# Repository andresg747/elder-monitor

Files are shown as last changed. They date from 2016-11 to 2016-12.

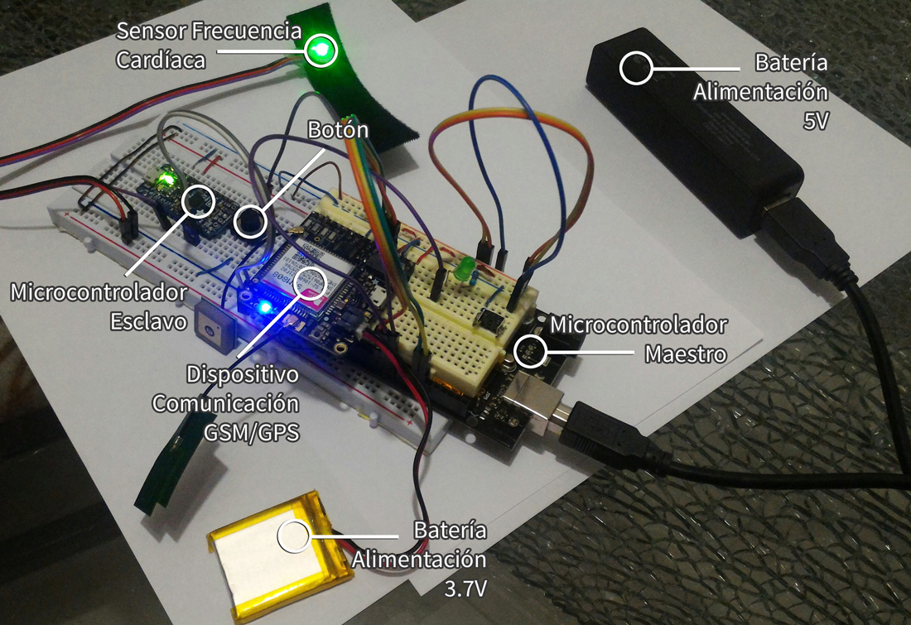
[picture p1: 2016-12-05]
Imágenes/Fotografia-descriptiva.jpg

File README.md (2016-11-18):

# Elder-Monitor
Dispositivo de monitorización para personas mayores. Localización GPS, lectura de frecuencia cardíaca, y botón de pánico con alertas vía SMS.

Arduino + Módulo GPS/GSM FONA (Adafruit) + PulseSensor (Adafruit). 

Proyecto para la acreditación de grado universitario.
Carrera: Ingeniería Electrónica en Computación.
Universidad Yacambu - Cabudare Edo. Lara, Venezuela.

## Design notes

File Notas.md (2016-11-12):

#### 09/10 2:49am
**Primera prueba - Botón de Pánico**

Al pulsar botón por 3 segundos, el led indicador enciende. Al soltarlo realiza las siguientes funciones:
+ Query de localización al módulo FONA.
+ Si el query es exitoso (GPSFIX), procede a enviar un msj de texto al número pregrabado con un mensaje de texto y un link (gmaps) con la localización exacta.

### 10/10 1:00am
**Mejorando Botón de Pánico**

Al pulsar el botón:

1. Chequea si hay GPSFIX y Envía Mensaje:
   + Si hay, actualiza latitud y longitud. Escribe en Serial. Actualiza IoT. Concatena valores al SMS y envía mensaje SOS.
   + Si no hay GPSFIX envía mensaje SOS invitando a revisar io.adafruit para chequear última localización disponible. Se mantendrá buscando hasta tener GPSFIX de nuevo y vuelve a enviar mensaje con localización "Nueva localización disponible: xxxxxxxxxxx ". (Recomendacion, flag en main loop).

### 10/10 2:00am

Creadas rutinas que se ejecutarán cada 15 seg y 60 seg respectivamente.
Para actualizar de manera constante Localización, Batería y (posteriormente) BPM.

### 12/10 11:30am
Agregado nuevo flag para enviar un único mensaje de alerta si el GPS no está disponible en ese instante. El mensaje invita al supervisor a revisar la última localización disponible en io.adafruit.com/andresg747/feeds/location

Se hicieron pruebas exitosas con función botón de pánico.

### 02/11 11:00pm
Al detectar fallas en tiempo de ejecución, se determinó que el stack de la SRAM estaba colapsando.
Se limpiaron variables y funciones varias intentando disminuir el espacio de almacenamiento utilizado por la SRAM y se corrigieron los fallos.
Se agregó una función de lectura de SMS que detecta comandos (.STATUS y .NUMERO) enviados por el supervisor y responde con SMS dependiendo del caso.

De igual manera, el espacio utilizado en SRAM sigue siendo alto. Aún falta agregar la lectura y cálculo de la frecuencia cardíaca.
Existe la probabilidad de que al agregar esta funcionalidad, la SRAM llegue a un nivel crítico que ponga en riesgo la estabilidad de la ejecución del programa

### 05/11 4:00pm
Se detectó un error que evitaba la conexión con el servidor de adafruit.io (MQTT broker) y cuya 'solución' fué des-comentar la línea #37 de la librería Adafruit_MQTT.h
Solución tomada del reporte del issue: https://github.com/adafruit/Adafruit_MQTT_Library/issues/54
Esta línea de código `#define MQTT_DEBUG` añade comentarios adicionales en la comunicación serial, referentes al envío de paquetes vía el protocolo MQTT. En el caso de este proyecto, se puede observar los paquetes enviados para localización, batería y BPM.

Se agregó un flag para el caso en el que se solicita .STATUS via SMS y ya se envió respuesta cuando no hay GPSFIX pero sin el flag nunca se enviaba el nuevo mensaje con la localización cuando se alcanzaba la conexión GPS.

**Sobre el uso de otro microcontrolador**
Como fué indicado anteriormente, se realizaron ciertos cambios en el código para optimizar el uso del espacio de almacenamiento, tanto en la memoria de programa (FLASH) pero principalmente en la memoria de ejecución (SRAM), del microcontrolador. Se determinó que el desbordamiento, o la sobre saturación de esta última memoria era la causante de que el programa en un momento determinado se reseteara.

Luego de ciertos cambios que se pueden observar en 4e97dd7, se eliminaron funciones inutilizadas, se redujo el espacio utilizado por variables cambiando su tipo a uno más eficiente y se evitó el uso de variables dinámicas. Esto aumentó el espacio de SRAM libre a casi 20%. Luego de este cambio, el dispositivo no volvió a resetearse de manera involuntaria.

Aún el proyecto, como está, no ha sido terminado. Se debe agregar una funcionalidad más para cubrir con los objetivos propuestos: **el sensor de frecuencia cardíaca**. Al revisar la librería utilizada por este sensor, se puede notar que su adición causaría, de nuevo, problemas de espacio en la SRAM. 

Dicho esto, por el poco tiempo que queda para la presentación del prototipo, surge la necesidad de agregar un segundo microcontrolador quedando el esquema de trabajo de la siguiente manera:

	+ Arduino Nano (ATMEGA328P 5V/16MHz) - Principal: Encargado del manejo del módulo de comunicación GSM/GPS, del procesamiento principal de variables y de la toma de decisiones en general.
	+ Trinket Pro (ATMEGA328P 5V/16MHz) - Secundario: Tiene como tarea única tarea el cálculo de la frecuencia cardíaca, y el envío de la misma a través de un canal serial hacia el microcontrolador principal.

El microcontrolador principal, se comunicará con el módulo FONA a través del un canal de SoftwareSerial (pines 10 y 11), y con el microcontrolador secundario a través del HardwareSerial (pines 0 y 1).

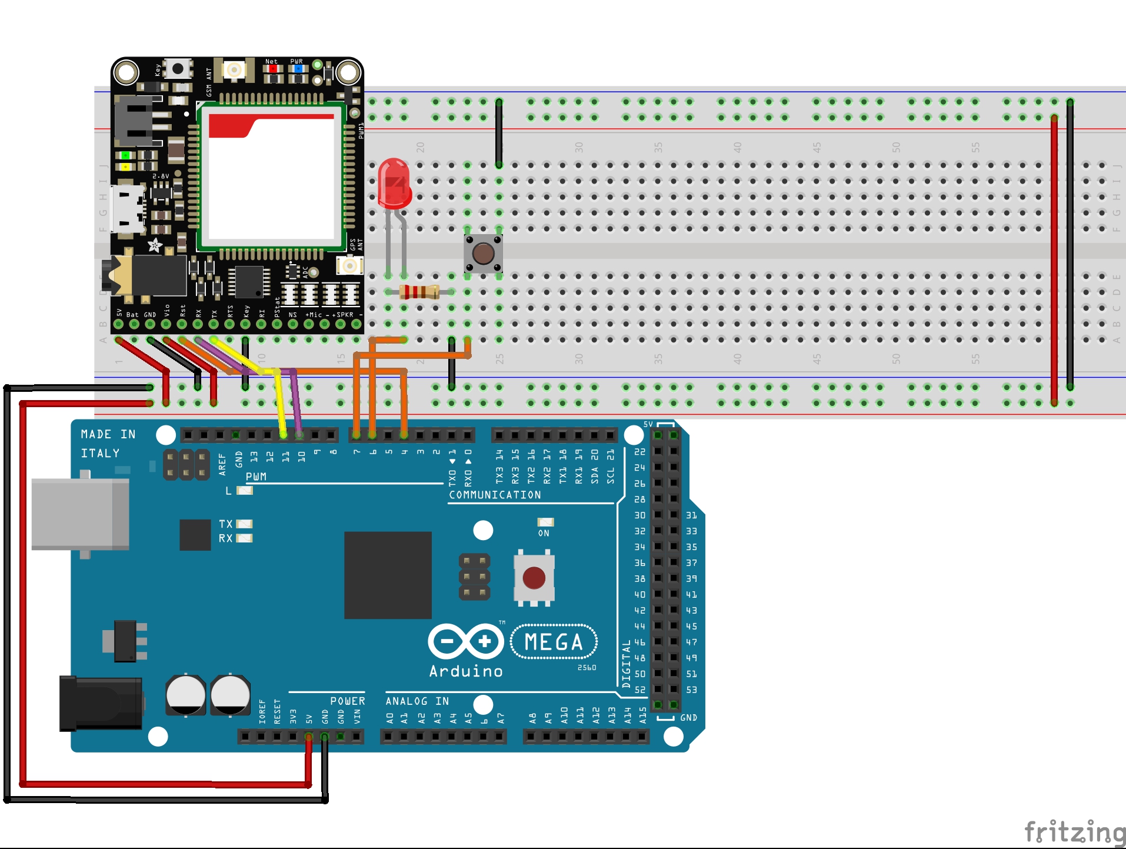
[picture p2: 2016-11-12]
Imágenes/fritzing-sketch_bb.jpg

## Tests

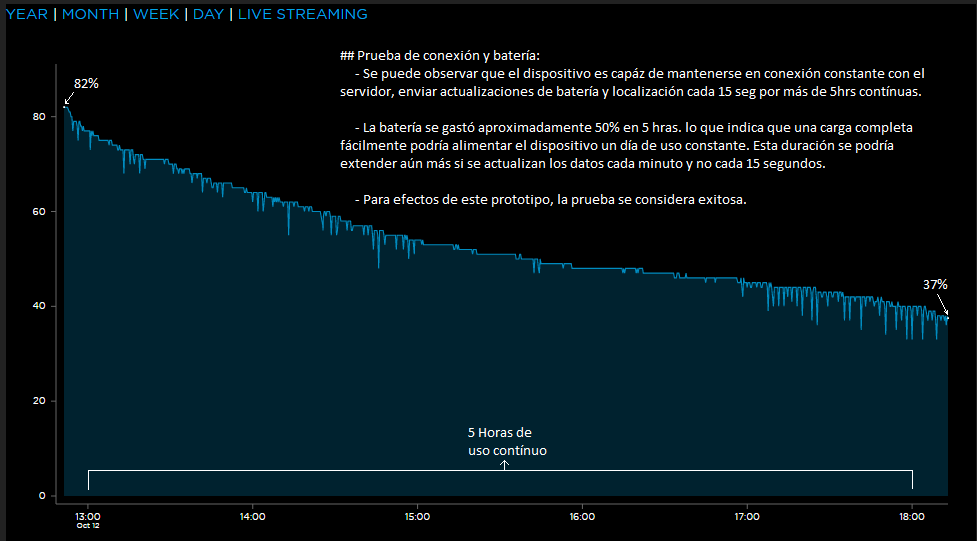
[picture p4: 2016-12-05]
Imágenes/Prueba Batería.png

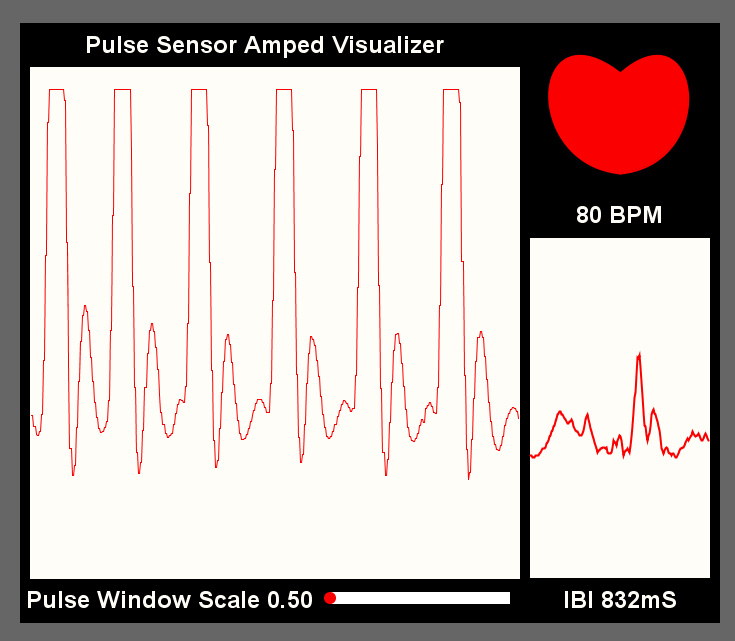
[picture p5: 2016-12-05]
Imágenes/BPM Prueba.png

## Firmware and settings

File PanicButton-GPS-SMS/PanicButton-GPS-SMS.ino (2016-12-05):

// Trabajo de Grado
// Andrés García

// Libraries
#include <Adafruit_SleepyDog.h>
#include <SoftwareSerial.h>
#include "Adafruit_FONA.h"
#include "Adafruit_MQTT.h"
#include "Adafruit_MQTT_FONA.h"
#include <Wire.h>

// Variables
int ledPin = 7;
int blinkPin = 9;
int buttonPin = 6;
int current;        // Estado del botón, activo en bajo
char bpm_chr = "";
int bpm = 0;
char bpm_string[3];
long millis_held;   // Milisegundos transcurridos
long secs_held;
long prev_secs_held;
byte previous = HIGH;
unsigned long firstTime;
char replybuffer[100];
byte SOS_flag=0; // Por si se intentó enviar SOS y aún no se tiene GPSFIX o nó se pudo enviar para reintentarlo
byte aux_Enviar_SMS = 0;
byte aux_Enviar_SMS_STATUS = 0;
byte STATUS_flag = 0;
uint16_t vbat;
float latitude, longitude, speed_kph, heading, altitude;
int smsnum; // Número de SMS en SIMCARD
// Para lectura SMS comando
char *num1 ="+584245328127";
char *num2;
char *num3;
char *num4;
char *num5;
char mensaje_txt[160];
char sender[13];

#define quinceSeg (1000UL * 15) // Base rutina c/15 Seg
#define unMin (1000UL * 60)  // Base rutina c/1 min
static unsigned long aux60 = 0 - unMin;
static unsigned long aux15 = 0 - quinceSeg;

// FONA pins
#define FONA_RX              11   // FONA serial RX pin.
#define FONA_TX              10   // FONA serial TX pin.
#define FONA_RST             5   // FONA reset pin

// FONA GPRS
#define FONA_APN             "internet.movistar.ve"
#define FONA_USERNAME        ""
#define FONA_PASSWORD        ""

// Adafruit IO
#define AIO_SERVER           "io.adafruit.com" 
#define AIO_SERVERPORT       1883
#define AIO_USERNAME         "andresg747"
#define AIO_KEY              "775d7bcfc4524333b664b941f3d82a1e"

// #define MAX_TX_FAILURES      3  // Maximum number of publish failures in a row before resetting the whole sketch.

// FONA instance & configuration
SoftwareSerial fonaSS = SoftwareSerial(FONA_TX, FONA_RX);     // FONA software serial connection.
Adafruit_FONA fona = Adafruit_FONA(FONA_RST);                 // FONA library connection.

Adafruit_MQTT_FONA mqtt(&fona, AIO_SERVER, AIO_SERVERPORT, AIO_USERNAME, AIO_KEY);

uint8_t txFailures = 0; // Cuantos publish fallidos consecutivos han ocurrido 

// Feeds
Adafruit_MQTT_Publish location_feed = Adafruit_MQTT_Publish(&mqtt, AIO_USERNAME "/feeds/location/csv");
Adafruit_MQTT_Publish battery_feed = Adafruit_MQTT_Publish(&mqtt, AIO_USERNAME "/feeds/battery");
Adafruit_MQTT_Publish bpm_feed = Adafruit_MQTT_Publish(&mqtt, AIO_USERNAME "/feeds/bpm");

void setup() {
  pinMode(blinkPin, OUTPUT);        // pin that will blink to your heartbeat!
  pinMode(ledPin, OUTPUT);
  digitalWrite(buttonPin, HIGH);  // Enciende PullUp 
  digitalWrite(ledPin,LOW);

  //Wire
  Wire.begin();        // Inicializa comunicación I2C

  //Inicializa Puerto Serial y Conexión Módulo
  Serial.begin(115200);
  Serial.println(F("Inicializando (puede tardar hasta 10 seg)"));
  fonaSS.begin(4800);
  if (!fona.begin(fonaSS)) {
    halt(F("FONA no disponible"));
  }

  Serial.println(F("FONA Conectado!"));

  // Wait for FONA to connect to cell network (up to 8 seconds, then watchdog reset).
  Serial.println(F("Conectando a la red..."));
  while (fona.getNetworkStatus() != 1) {
    delay(500);
  }
  fona.setGPRSNetworkSettings(F(FONA_APN));
  delay(1000);
  Serial.println(F("Dehabilita GPRS"));
  fona.enableGPRS(false);
  delay(1000);
  Serial.println(F("Habilita GPRS"));
  while (!fona.enableGPRS(true)) {
    Serial.println(F("No se pudo conectar a la red de datos..."));
    delay(1000);
    Serial.println(F("Dehabilita GPRS"));
    fona.enableGPRS(false);
    delay(1000);
  }
  Serial.println(F("Conectado a la red de datos."));
  delay(1000);

  // Now make the MQTT connection.
  int8_t ret = mqtt.connect();
  if (ret != 0) {
    Serial.println(mqtt.connectErrorString(ret));
    Serial.println(F("No se pudo conectar a servidor MQTT..."));
  }
  Serial.println(F("MQTT Conectado!"));

  // Initial GPS read
  bool gpsFix = fona.getGPS(&latitude, &longitude, &speed_kph, &heading, &altitude);

  // Enable GPS.
  fona.enableGPS(true);

  delay(500);

  borrarSMS();
  checkGPS();
}

void loop() {
  //MQTT_connect();
  checkbutton();

  if ((long)(millis() - aux60) >= unMin){
    aux60 += unMin;
    // ++++++++  Cada 60 seg
    checkGPS();
    checkBattery();

  }else if((long)(millis() - aux15) >= quinceSeg){
    aux15 += quinceSeg;
    // ++++++++  Cada 15 seg
    checkBPM();
    leerSMS();

    //Veriicamos flag para envío de SMS Alerta
    if(SOS_flag == 1){
      sendSMS_SOS();
    }
    if(STATUS_flag){
      sendSMS_STATUS();
    }
  }

  delay(10);
}

void leerSMS(){
  smsnum = fona.getNumSMS();
  if(smsnum > 0){
    Serial.println(F("Nuevo Mensaje de Texto"));
    uint8_t n = 1; 
    while (true) {
      uint16_t smslen;

      Serial.print(F("\n\rReading SMS #")); Serial.println(n);
     uint8_t len = fona.readSMS(n, replybuffer, 250, &smslen); // pass in buffer and max len!
     // if the length is zero, its a special case where the index number is higher
     // so increase the max we'll look at!
     if (len == 0) {
      Serial.println(F("[empty slot]"));
      n++;
      continue;
     }
     if (! fona.getSMSSender(n, sender, sizeof(sender))) {
       // failed to get the sender?
      sender[0] = 0;
     }

     Serial.print(F("***** SMS #")); Serial.print(n);
     Serial.print(" ("); Serial.print(len); Serial.println(F(") bytes *****"));
     Serial.println(replybuffer);
     Serial.print(F("From: ")); Serial.println(sender);
     Serial.println(F("*****"));
     String mensaje = replybuffer;

     // if (strcasecmp(replybuffer, ".STATUS") == 0) {
     if (mensaje.substring(0, 7) == ".STATUS") {
       // Comando Status
      Serial.println(F("/////////////////////"));
      Serial.println(F("Solicita Status"));
      aux_Enviar_SMS_STATUS = 1;
      sendSMS_STATUS();
     }
     // if (strcasecmp(replybuffer, ".NUMERO") == 0) {
     if (mensaje.substring(0, 7) == ".NUMERO") {
      // Comando Cambiar Número
      Serial.println(F("Comenzando parsing..."));

      delay(500);
      char *token;
      token = strtok(replybuffer,",");
      if (token == NULL){
        Serial.println(F("No hay tokens."));
        break;
      }
      num1 = token;
      strncpy(num1,num1+8,14);
      Serial.print("Numero 1: ");
      Serial.println(num1);
      delay(500);

      token = strtok(NULL,",");
      num2 = token;
      Serial.print("Numero 2: ");
      Serial.println(num2);
      delay(500);

      token = strtok(NULL,",");
      num3 = token;
      Serial.print("Numero 3: ");
      Serial.println(num3);
      delay(500);

      token = strtok(NULL,",");
      num4 = token;
      Serial.print("Numero 4: ");
      Serial.println(num4);
      delay(500);

      token = strtok(NULL,",");
      num5 = token;
      Serial.print("Numero 5: ");
      Serial.println(num5);
      delay(1000);
     }

     delay(2000);
     break;
   } 
   borrarSMS(); 
 }
 Serial.print(F("Hay "));
 Serial.print((smsnum));
 Serial.println(F(" SMS's en la SIM CARD."));
}

void checkbutton(){
  current = digitalRead(buttonPin);

  // if the button state changes to pressed, remember the start time 
  if (current == LOW && previous == HIGH && (millis() - firstTime) > 200) {
    firstTime = millis();
  }

  millis_held = (millis() - firstTime);
  secs_held = millis_held / 1000;
  // Chequea si el botón realmente fue pulsado (debounce)
  if (millis_held > 50) {
    // Pulsado por más de 2800ms
    if (current == LOW && secs_held > prev_secs_held ) {
      if (millis_held > 2900 )
      {
        digitalWrite(ledPin,HIGH);
      }
    }
    if (current == HIGH && previous == LOW) {
      if (millis_held >= 3000) {
        aux_Enviar_SMS = 1;
        sendSMS_SOS();
      }
    }
  }

  previous = current;
  prev_secs_held = secs_held;

  if(current == HIGH)
    digitalWrite(ledPin,LOW);
}

// Envio Mensaje Socorro
void sendSMS_SOS(){
  // Lectura GPS
  bool gpsFix = fona.getGPS(&latitude, &longitude, &speed_kph, &heading, &altitude);

  if(gpsFix){
    Serial.print(F("Latitud: "));
    Serial.print(latitude, 5);
    Serial.println("");

    Serial.print(F("Longitud: "));
    Serial.print(longitude, 5);
    Serial.println("");

    // Concateno mensaje con Latitud y Longitud
    strcpy(mensaje_txt, "SOS! Ubicacion: https://maps.google.com/?q=");
    dtostrf(latitude,6,5,&mensaje_txt[strlen(mensaje_txt)]);
    strcat(mensaje_txt,",");
    dtostrf(longitude,6,5,&mensaje_txt[strlen(mensaje_txt)]);
    if(bpm == 0){
      strcat(mensaje_txt," BPM no disponible.");
    }else{
      sprintf(bpm_string, "%d", bpm);
      strcat(mensaje_txt," BPM: ");
      strcat(mensaje_txt,bpm_string);
      strcat(mensaje_txt," ");
    }

    // Imprimo mensaje en serial
    Serial.println(mensaje_txt);

    // Enviar mensaje a todos
    if (strlen(num1) > 1){
      if (!fona.sendSMS(num1, mensaje_txt)) {
        Serial.println(F("No se pudo enviar SMS"));
        SOS_flag = 1;
      } else {
        Serial.println(F("Mensaje enviado con exito!"));
        SOS_flag = 0;
        aux_Enviar_SMS = 0;
      }
    }
    if (strlen(num2) > 1){
      if (!fona.sendSMS(num2, mensaje_txt)) {
        Serial.println(F("No se pudo enviar SMS"));
      } else {
        Serial.println(F("Mensaje enviado con exito!"));
      }
    }
    if (strlen(num3) > 1){
      if (!fona.sendSMS(num3, mensaje_txt)) {
        Serial.println(F("No se pudo enviar SMS"));
      } else {
        Serial.println(F("Mensaje enviado con exito!"));
      }
    }
    if (strlen(num4) > 1){
      if (!fona.sendSMS(num4, mensaje_txt)) {
        Serial.println(F("No se pudo enviar SMS"));
      } else {
        Serial.println(F("Mensaje enviado con exito!"));
      }
    }
    if (strlen(num5) > 1){
      if (!fona.sendSMS(num5, mensaje_txt)) {
        Serial.println(F("No se pudo enviar SMS"));
      } else {
        Serial.println(F("Mensaje enviado con exito!"));
      }
    }

    // Actualiza IoT
  }else if (!gpsFix){

    SOS_flag = 1;
    Serial.println(F("Para SMS-SOS Aun no hay GPSFIX, se intentara de nuevo. "));
    if(aux_Enviar_SMS){
      Serial.println("Creando nuevo mensaje");delay(100);
      strcpy(mensaje_txt, "SOS! GPS no disponible. Ultima ubicacion: https://io.adafruit.com/andresg747/ Se notificara cuando GPS este disponible. ");
      if(bpm == 0){
        strcat(mensaje_txt," BPM no disponible.");
      }else{
        sprintf(bpm_string, "%d", bpm);
        strcat(mensaje_txt," BPM: ");
        strcat(mensaje_txt,bpm_string);
        strcat(mensaje_txt," ");
      }
      // Enviar a todos los números:
      if (strlen(num1) > 1){
        if (!fona.sendSMS(num1, mensaje_txt)) {
          Serial.println(F("No se pudo enviar SMS"));
        } else {
          Serial.println(F("Mensaje enviado con exito!"));
          aux_Enviar_SMS = 0;
        }
      }
      if (strlen(num2) > 2){
        if (!fona.sendSMS(num2, mensaje_txt)) {
          Serial.println(F("No se pudo enviar SMS"));
        } else {
          Serial.println(F("Mensaje enviado con exito!"));
        }
      }
      if (strlen(num3) > 2){
        if (!fona.sendSMS(num3, mensaje_txt)) {
          Serial.println(F("No se pudo enviar SMS"));
        } else {
          Serial.println(F("Mensaje enviado con exito!"));
        }
      }
      if (strlen(num4) > 2){
        if (!fona.sendSMS(num4, mensaje_txt)) {
          Serial.println(F("No se pudo enviar SMS"));
        } else {
          Serial.println(F("Mensaje enviado con exito!"));
        }
      }
      if (strlen(num5) > 2){
        if (!fona.sendSMS(num5, mensaje_txt)) {
          Serial.println(F("No se pudo enviar SMS"));
        } else {
          Serial.println(F("Mensaje enviado con exito!"));
        }
      }
    }
  }
}

// Envio Mensaje Previa solicitud STATUS
void sendSMS_STATUS(){
  // Lectura GPS
  bool gpsFix = fona.getGPS(&latitude, &longitude, &speed_kph, &heading, &altitude);

  if(gpsFix){
    // Concateno mensaje con Latitud y Longitud
    strcpy(mensaje_txt, "Ubicacion: https://maps.google.com/?q=");
    dtostrf(latitude,6,5,&mensaje_txt[strlen(mensaje_txt)]);
    strcat(mensaje_txt,",");
    dtostrf(longitude,6,5,&mensaje_txt[strlen(mensaje_txt)]);
    if(bpm == 0){
      strcat(mensaje_txt," BPM no disponible.");
    }else{
      sprintf(bpm_string, "%d", bpm);
      strcat(mensaje_txt," BPM: ");
      strcat(mensaje_txt,bpm_string);
      strcat(mensaje_txt," ");
    }

    // Imprimo mensaje en serial
    Serial.println(mensaje_txt);

    //Envío mensaje

    if (!fona.sendSMS(sender, mensaje_txt)) {
      Serial.println(F("No se pudo enviar SMS"));
    } else {
      Serial.println(F("Mensaje enviado con exito!"));
      STATUS_flag = 0;
    }

    // Actualiza IoT
  }else if (!gpsFix){
    STATUS_flag = 1;
    Serial.println(F("Para SMS-STATUS Aun no hay GPSFIX, se intentara de nuevo."));
    if(aux_Enviar_SMS_STATUS){
      strcpy(mensaje_txt, "GPS no disponible. Ultima ubicacion: https://io.adafruit.com/andresg747/ Se notificara de inmediato cuando GPS este disponible. ");
      if(bpm == 0){
        strcat(mensaje_txt," BPM no disponible.");
      }else{
        sprintf(bpm_string, "%d", bpm);
        strcat(mensaje_txt," BPM: ");
        strcat(mensaje_txt,bpm_string);
        strcat(mensaje_txt," ");
      }

      if (!fona.sendSMS(sender, mensaje_txt)) {
        Serial.println(F("No se pudo enviar SMS"));
      } else {
        Serial.println(F("Mensaje enviado con exito!"));
        aux_Enviar_SMS_STATUS = 0;
      }

    }
  }
}

// Lectura y actualización de GPS
void checkGPS(){
  bool gpsFix = fona.getGPS(&latitude, &longitude, &speed_kph, &heading, &altitude);

  if(gpsFix){
    Serial.print(F("Latitud: "));
    Serial.print(latitude, 5);
    Serial.println("");

    Serial.print(F("Longitud: "));
    Serial.print(longitude, 5);
    Serial.println("");

    // Actualiza IoT
    logLocation(latitude, longitude, altitude, location_feed);

  }else{
    Serial.println(F("GPS No disponible."));
  }
}

void checkBattery(){
  if (! fona.getBattPercent(&vbat)) {
    Serial.println(F("No pudo obtener nivel de Bateria"));
  } else {
    Serial.print(F("Porcentaje Bateria = ")); Serial.print(vbat); Serial.println(F("%"));
  }
  log(vbat, battery_feed);
}

void checkBPM(){
  Serial.println(F("Solicitando BPM"));
  Wire.requestFrom(1, 1);     // Solicita 1 byte de dispositivo esclavo #1
  while (Wire.available()) {
    bpm_chr = Wire.read();
    bpm = (int)bpm_chr;
    if(bpm > 165 || bpm < 35){
      Serial.println("BPM: No Disponible.");
      bpm = 0;
    }else{
      Serial.print("BPM: ");
      Serial.println(bpm);
      log(bpm, bpm_feed);
    }
  }
}

// Manejo de errores
void halt(const __FlashStringHelper *error) {
  Serial.println(error);
  while (1) {
    digitalWrite(ledPin, LOW);
    delay(100);
    digitalWrite(ledPin, HIGH);
    delay(100);
  }
}

// Log battery
void log(uint32_t indicator, Adafruit_MQTT_Publish& publishFeed) {
  // Publish
  Serial.print(F("Publicando ")); Serial.println(indicator);
  if (!publishFeed.publish(indicator)) {
    Serial.println(F("Publish failed!"));
    txFailures++;
  }
  else {
    Serial.println(F("Publish succeeded!"));
    txFailures = 0;
  }
}

// Serialize the lat, long, altitude to a CSV string that can be published to the specified feed.
void logLocation(float latitude, float longitude, float altitude, Adafruit_MQTT_Publish& publishFeed) {
  // Initialize a string buffer to hold the data that will be published.
  char sendBuffer[120];
  memset(sendBuffer, 0, sizeof(sendBuffer));
  int index = 0;

  // Start with '0,' to set the feed value.  The value isn't really used so 0 is used as a placeholder.
  sendBuffer[index++] = '0';
  sendBuffer[index++] = ',';

  // Now set latitude, longitude, altitude separated by commas.
  dtostrf(latitude, 2, 6, &sendBuffer[index]);
  index += strlen(&sendBuffer[index]);
  sendBuffer[index++] = ',';
  dtostrf(longitude, 3, 6, &sendBuffer[index]);
  index += strlen(&sendBuffer[index]);
  sendBuffer[index++] = ',';
  dtostrf(altitude, 2, 6, &sendBuffer[index]);

  // Finally publish the string to the feed.
  Serial.print(F("Publicando Localizacion: "));
  Serial.println(sendBuffer);
  if (!publishFeed.publish(sendBuffer)) {
    Serial.println(F("Publish failed!"));
    txFailures++;
  }
  else {
    Serial.println(F("Publish succeeded!"));
    txFailures = 0;
  }
}

void borrarSMS(){
  smsnum = fona.getNumSMS();
  Serial.print(F("Hay "));
  Serial.print((smsnum));
  Serial.println(F(" SMS's en la SIM CARD."));
  if(smsnum > 0){
    for (int n = 1; n <= smsnum; ++n)
    {
      Serial.println(F("Borrando Mensaje #: "));
      Serial.println((n));
      fona.deleteSMS(n);
      delay(2000);
    }
  }
}

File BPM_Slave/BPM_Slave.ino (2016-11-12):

/*  Pulse Sensor Amped 1.4    by Joel Murphy and Yury Gitman   http://www.pulsesensor.com

  ----------------------  Notes ----------------------  ----------------------
  This code:
  1) Blinks an LED to User's Live Heartbeat   PIN 13
  2) Fades an LED to User's Live HeartBeat
  3) Determines BPM
  4) Prints All of the Above to Serial

  Read Me:
  https://github.com/WorldFamousElectronics/PulseSensor_Amped_Arduino/blob/master/README.md
  ----------------------       ----------------------  ----------------------
*/

#include <Wire.h>
// SDA PIN 4
// SCL PIN 5

//  Variables
int pulsePin = 0;                 // Pulse Sensor purple wire connected to analog pin 0
int blinkPin = 13;                // pin to blink led at each beat
int fadePin = 5;                  // pin to do fancy classy fading blink at each beat
int fadeRate = 0;                 // used to fade LED on with PWM on fadePin

// Volatile Variables, used in the interrupt service routine!
volatile int BPM = 0;                   // int that holds raw Analog in 0. updated every 2mS
volatile int Signal;                // holds the incoming raw data
volatile int IBI = 600;             // int that holds the time interval between beats! Must be seeded!
volatile boolean Pulse = false;     // "True" when User's live heartbeat is detected. "False" when not a "live beat".
volatile boolean QS = false;        // becomes true when Arduoino finds a beat.

// Regards Serial OutPut  -- Set This Up to your needs
static boolean serialVisual = false;   // Set to 'false' by Default.  Re-set to 'true' to see Arduino Serial Monitor ASCII Visual Pulse


void setup() {
  Wire.begin(1);                // join i2c bus with address #1
  Wire.onRequest(requestEvent); // register event
  pinMode(blinkPin, OUTPUT);        // pin that will blink to your heartbeat!
  pinMode(fadePin, OUTPUT);         // pin that will fade to your heartbeat!
  Serial.begin(115200);             // we agree to talk fast!
  interruptSetup();                 // sets up to read Pulse Sensor signal every 2mS
  // IF YOU ARE POWERING The Pulse Sensor AT VOLTAGE LESS THAN THE BOARD VOLTAGE,
  // UN-COMMENT THE NEXT LINE AND APPLY THAT VOLTAGE TO THE A-REF PIN
  //   analogReference(EXTERNAL);
}


//  Where the Magic Happens
void loop() {

  //serialOutput() ;

  if (QS == true) {    // A Heartbeat Was Found
    // BPM and IBI have been Determined
    // Quantified Self "QS" true when arduino finds a heartbeat
    fadeRate = 255;         // Makes the LED Fade Effect Happen
    // Set 'fadeRate' Variable to 255 to fade LED with pulse
    //serialOutputWhenBeatHappens();   // A Beat Happened, Output that to serial.
    QS = false;                      // reset the Quantified Self flag for next time
  }

  //ledFadeToBeat();                      // Makes the LED Fade Effect Happen
  delay(20);                             //  take a break
}

void requestEvent() {
  Wire.write(BPM);
}

void ledFadeToBeat() {
  fadeRate -= 15;                         //  set LED fade value
  fadeRate = constrain(fadeRate, 0, 255); //  keep LED fade value from going into negative numbers!
  analogWrite(fadePin, fadeRate);         //  fade LED
}

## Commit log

2016-10-10 Programa. Initial Commit
    09/10 2:49am == Primera prueba [EXITOSA]
    Botón de Pánico - Al pulsar botón por 3 segundos, el led indicador
    enciende. Al soltarlo realiza las siguientes funciones:
    - Query de localización al módulo FONA.
    - Si el query es exitoso (GPSFIX), procede a enviar un msj de texto al
    número pregrabado con un mensaje de texto y un link (gmaps) con la
    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
2016-10-10 Actualización Notas
    Corregidas anotaciones algoritmo de botón de pánico.
2016-10-10 Mejorando Botón de Pánico
    Creadas rutinas que se ejecutarán cada 15 seg y 60 seg respectivamente.
    Para actualizar de manera constante Localización, Batería y
    (posteriormente) BPM.
2016-10-12 Nuevo flag y correcciones varias.
    Prueba exitosa botón de pánico.
2016-11-03 Comandos SMS y Optimizaciones de Memoria
2016-11-03 Actualizaciones 02/11
    Lectura SMS y Optimizaciones de Memoria
2016-11-12 Añadidas librerías, y código para arduino Master y Slave.
    [fritzing-sketch.fzz]
2016-12-05 Cambios Pre - Defensa
    Agregado:
    1- Funciones necesarias para la implementación de una aplicación
    desarrollada en Android para controlar todo el dispositivo.
    2- Ahora el dispositivo permite la configuración de hasta 5 números de
    teléfono para envío de alertas.
    3- Se corrigen errores de manejo de algunas cadenas y se realizan
    algunos cambios en pro de optimizar la ejecución en general.
    [PanicButton-GPS-SMS.ino, codigoextra.ino]
